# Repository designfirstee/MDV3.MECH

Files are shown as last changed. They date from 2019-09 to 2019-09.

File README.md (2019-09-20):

# MDV3.MECH

----
## What is MDv3?

Тhe First Open Design Metal Detector for the Industry. This is not a metal detector for treasure hunting or airport security. This is a metal detector for manufacturers, the recycling and processing industry.

- MDv3 can protect the output production from metal particles

- MDv3 can protect machines from broken off parts from the other machines on the production line

- MDv3 can protect the input of processing manufacturing

- MDv3 can be used as an Education and Research platform

----
## What files are in this repository?

1. Technical drawings - Mechanical drawings, describing the complete mechanical design of MDv3's reference design. MDv3 drawings follow worldwide accepted ISO standards for formatting.
  * MDv3 main technical drawing with BOM
  * Enclosure
  * Cover
  * Frame
  * Reel
2. 3D Models - STL files for 3D printing, ready for use with your favorite 3D slicer.

----
## Why?
# Innovation

*Industry 4.0 requires higher level of optimization and control by the user, therefore an open design industrial metal detector is the natural step in industrial engineering, for higher output manufacturing*

**Open design breaks the vendor dependencies** and enables the system integrators to create the optimum solutions for their end users

----
## Changelog
* 20-Sep-2019 Initial reference design of MDv3

----
## Thanks to
* Manoel Yanev - For being able to turn DesignFirst's concept of MDv3 into mechanical design after studying the previous MDv2 design
* Ivan Petrov - For testing together one of the first MDv3 prototypes (internal codenames - MDv3 Red and MDv3 White)
* Mitko Vasilev, Georgi Tonchev - For the feedback during publication of the design files and DesignFirst's website

----
# Learn more at [https://designfirst.eu](https://designfirst.eu).

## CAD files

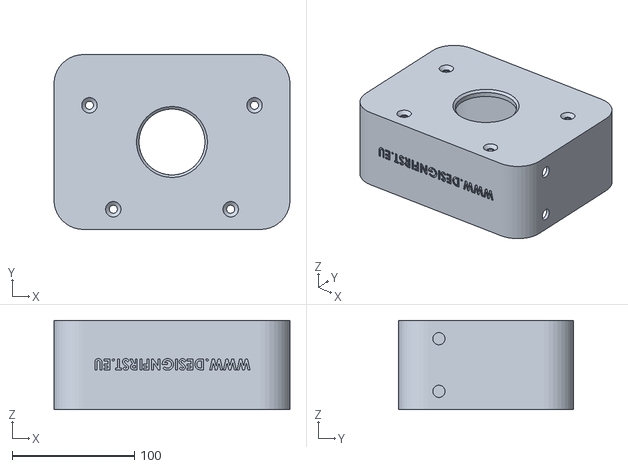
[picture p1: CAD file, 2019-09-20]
3D-models/MD-3-00.00.00.01.STL
193.0 x 143.0 x 73.0

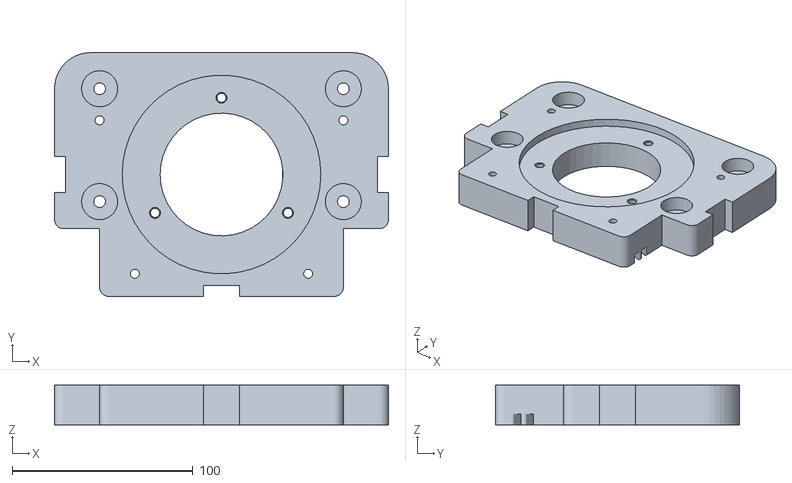
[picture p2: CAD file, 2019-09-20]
3D-models/MD-3-01.00.00.01.STL
185.0 x 135.0 x 22.0

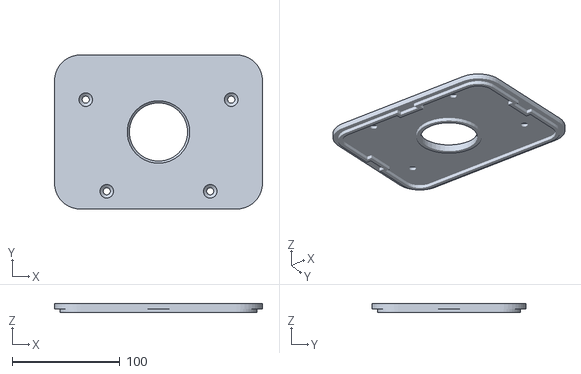
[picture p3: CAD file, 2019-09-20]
3D-models/MD-3-00.00.00.02.STL
193.0 x 143.0 x 8.00

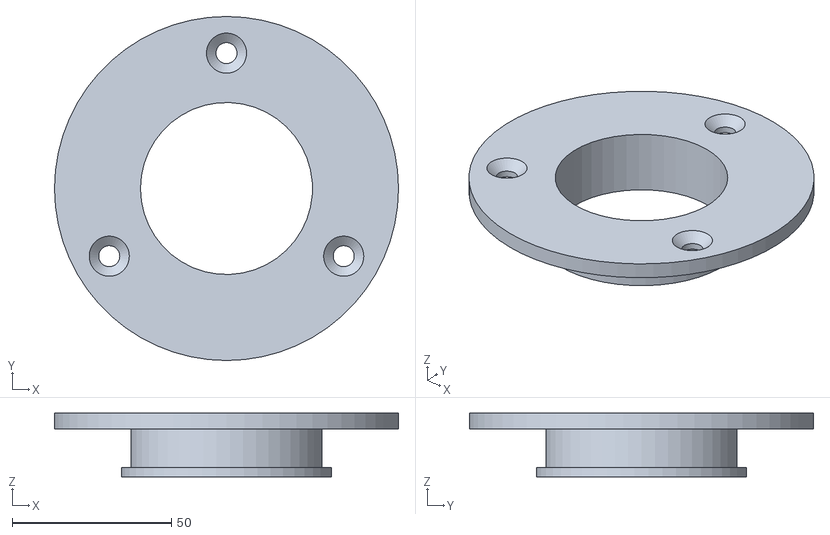
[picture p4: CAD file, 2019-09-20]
3D-models/MD-3-01.00.00.02.STL
108.0 x 108.0 x 20.0

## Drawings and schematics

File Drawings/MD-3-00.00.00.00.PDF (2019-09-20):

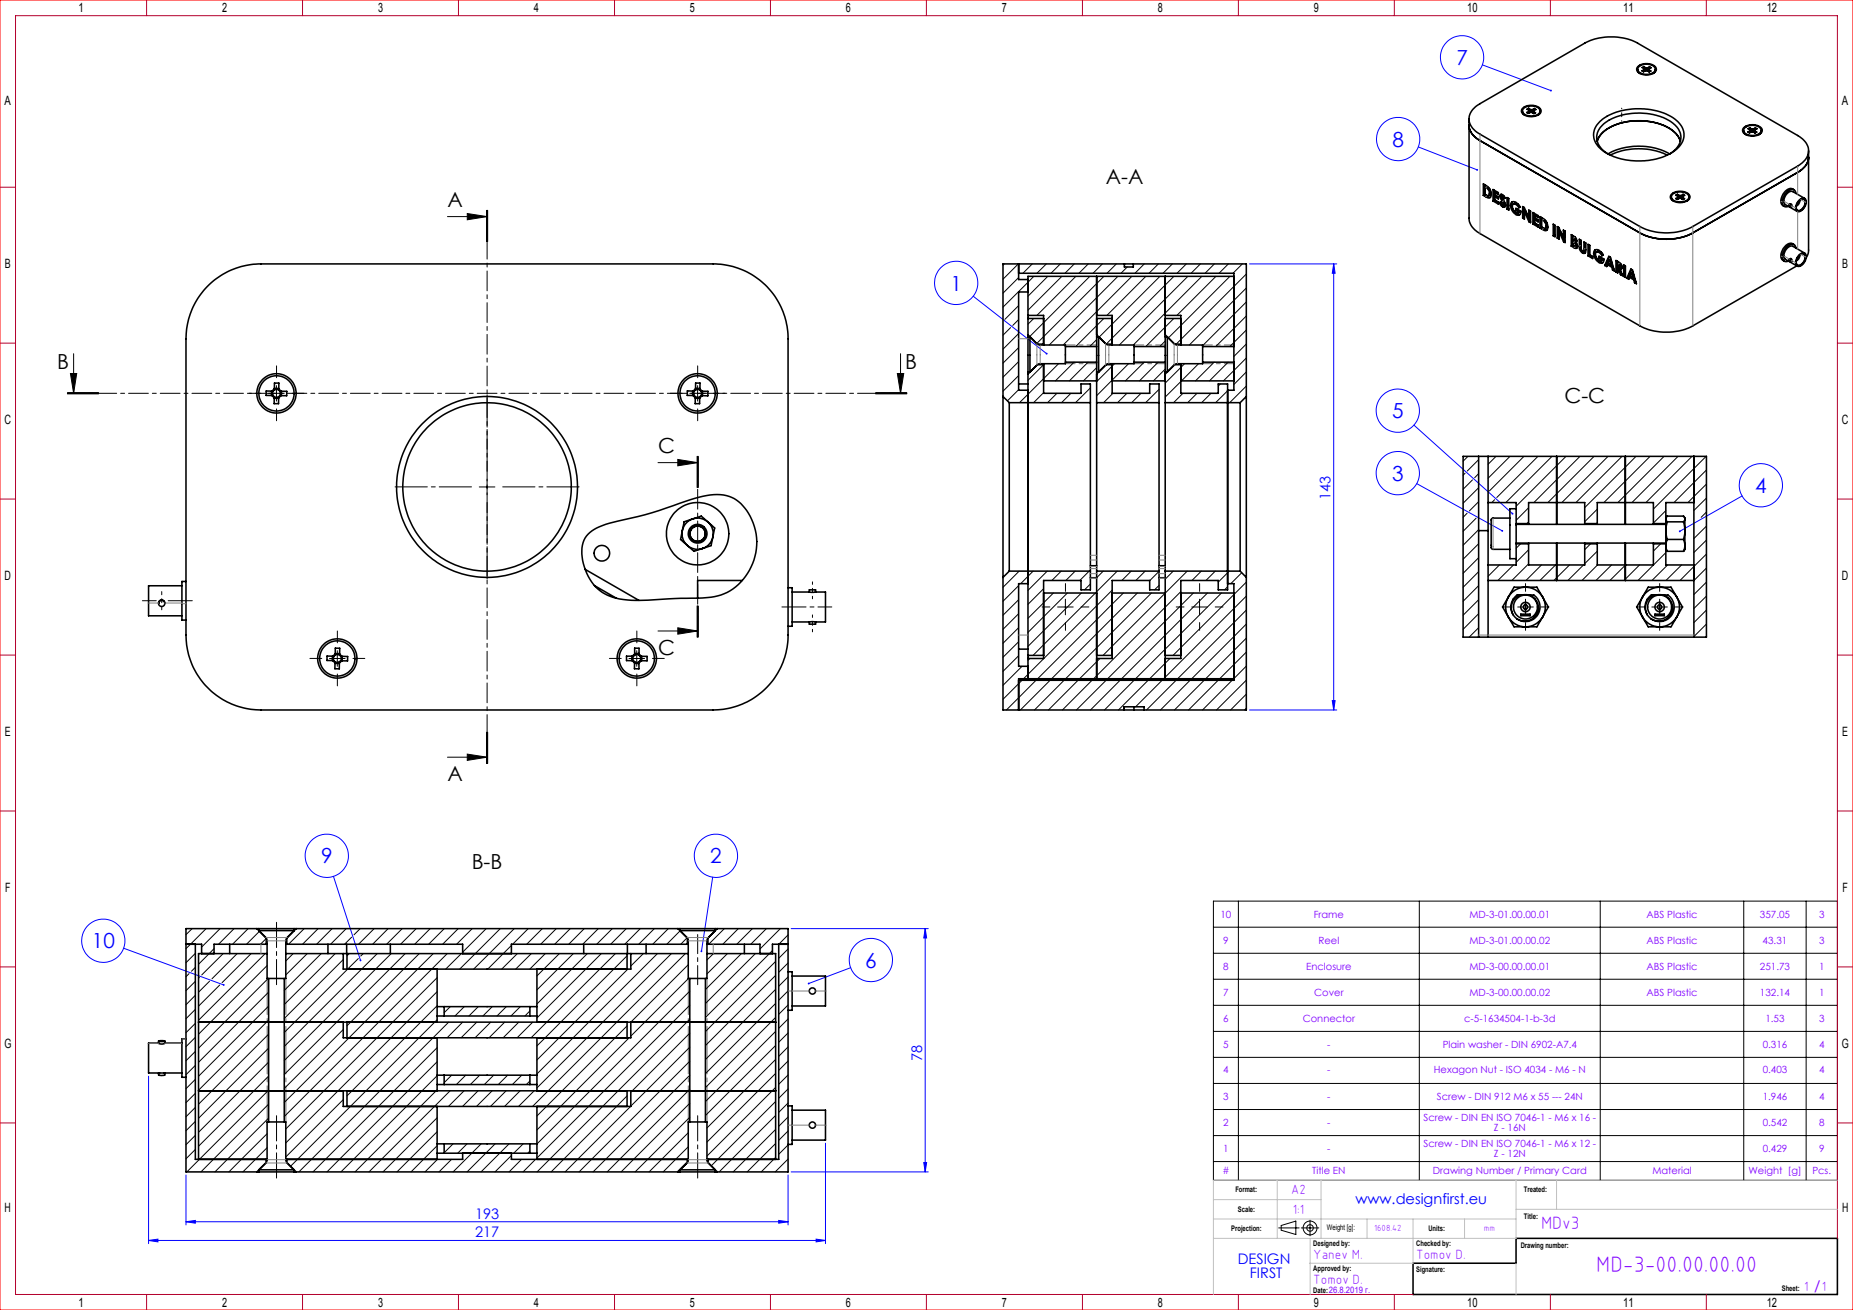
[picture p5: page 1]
Weight [g]:

10 | Frame | MD-3-01.00.00.01 | ABS Plastic | 357.05 | 3
9 | Reel | MD-3-01.00.00.02 | ABS Plastic | 43.31 | 3
8 | Enclosure | MD-3-00.00.00.01 | ABS Plastic | 251.73 | 1
7 | Cover | MD-3-00.00.00.02 | ABS Plastic | 132.14 | 1
6 | Connector | c-5-1634504-1-b-3d | | 1.53 | 3
5 | - | Plain washer - DIN 6902-A7.4 | | 0.316 | 4
4 | - | Hexagon Nut - ISO 4034 - M6 - N | | 0.403 | 4

3 | - | Screw - DIN 912 M6 x 55 --- 24N | | 1.946 | 4
2 | - | Screw - DIN EN ISO 7046-1 - M6 x 16 -Z - 16N | | 0.542 | 8
1 | - | Screw - DIN EN ISO 7046-1 - M6 x 12 -Z - 12N | | 0.429 | 9

# | Title EN | Drawing Number / Primary Card | Material | Weight [g] | Pcs.
Format: | A2 | www.designfirst.eu | Treated:
Scale: | 1:1
DESIGN FIRST | Designed by: Yanev M. | Checked by: Tomov D. | Drawing number: MD-3-00.00.00.00 Sheet: 1 /1

Approved by: Tomov D. Date: 26.8.2019 г. | Signature:

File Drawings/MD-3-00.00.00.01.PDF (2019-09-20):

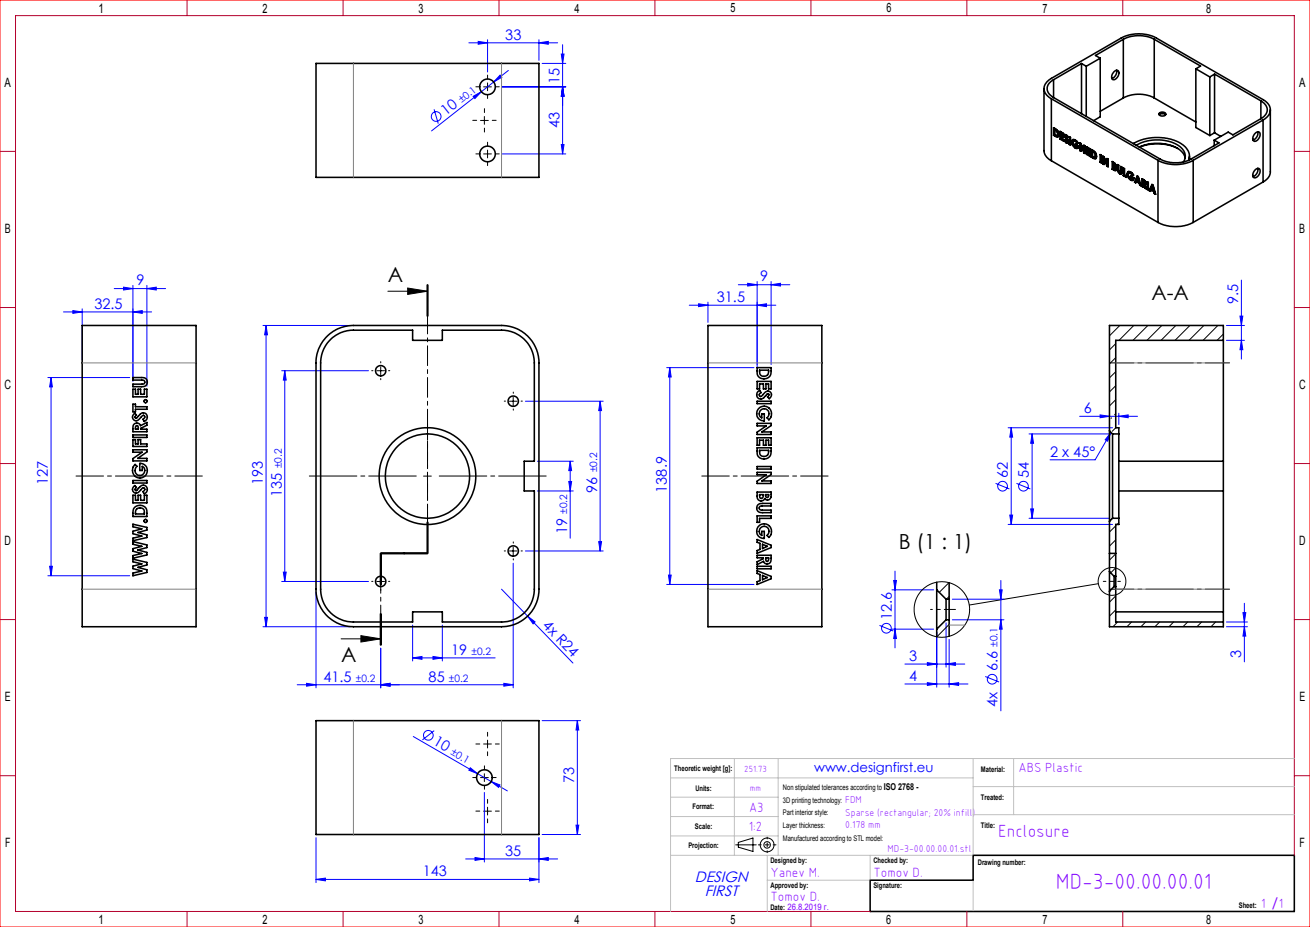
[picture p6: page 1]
Part interior style:; Sparse (rectangular; 20% infill)

Theoretic weight [g]: | 251.73 | www.designfirst.eu | Material: | ABS Plastic

Units: | mm | Non stipulated tolerances according to ISO 2768 -3D printing technology: FDM Layer thickness: 0.178 mm Manufactured according to STL model: MD-3-00.00.00.01.stl
Format: | A3
Scale: | 1:2 | | Title: Enclosure

Treated:

DESIGN FIRST | Designed by: Yanev M. | Checked by: Tomov D. | Drawing number: MD-3-00.00.00.01 Sheet: 1 / 1

Approved by: Tomov D. Date: 26.8.2019 г. | Signature:

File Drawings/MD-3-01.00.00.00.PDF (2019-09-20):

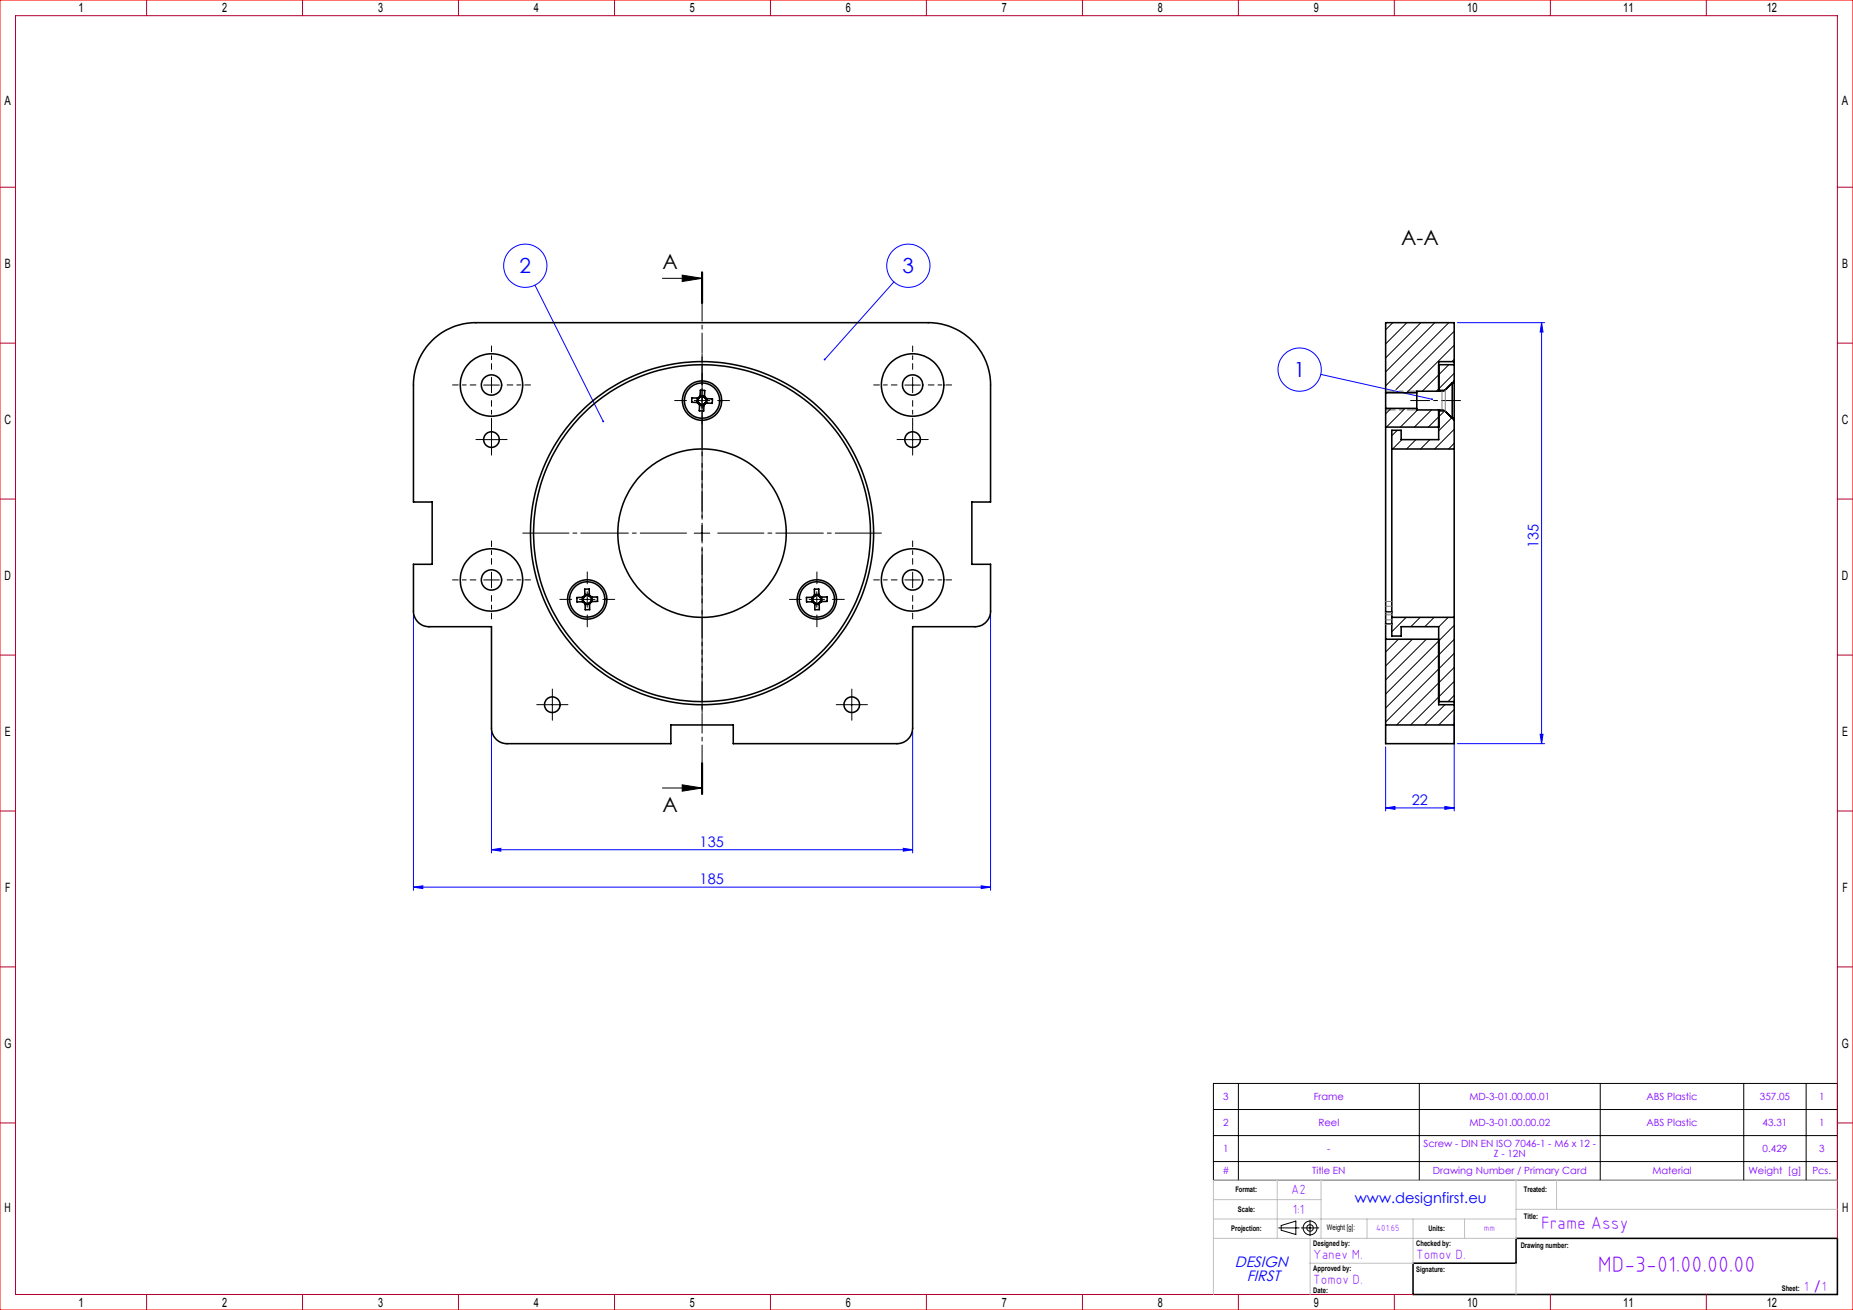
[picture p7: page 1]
Units:; Frame Assy

3 | Frame | MD-3-01.00.00.01 | ABS Plastic | 357.05 | 1
2 | Reel | MD-3-01.00.00.02 | ABS Plastic | 43.31 | 1
1 | - | Screw - DIN EN ISO 7046-1 - M6 x 12 -Z - 12N | | 0.429 | 3

# | Title EN | Drawing Number / Primary Card | Material | Weight [g] | Pcs.
Format: | A2 | www.designfirst.eu | Treated:
Scale: | 1:1
Projection: | | Weight [g]: | 401.65
DESIGN FIRST | Designed by: Yanev M. | Checked by: Tomov D. | Drawing number: MD-3-01.00.00.00 Sheet: 1 /1

Approved by: Tomov D. Date: | Signature:

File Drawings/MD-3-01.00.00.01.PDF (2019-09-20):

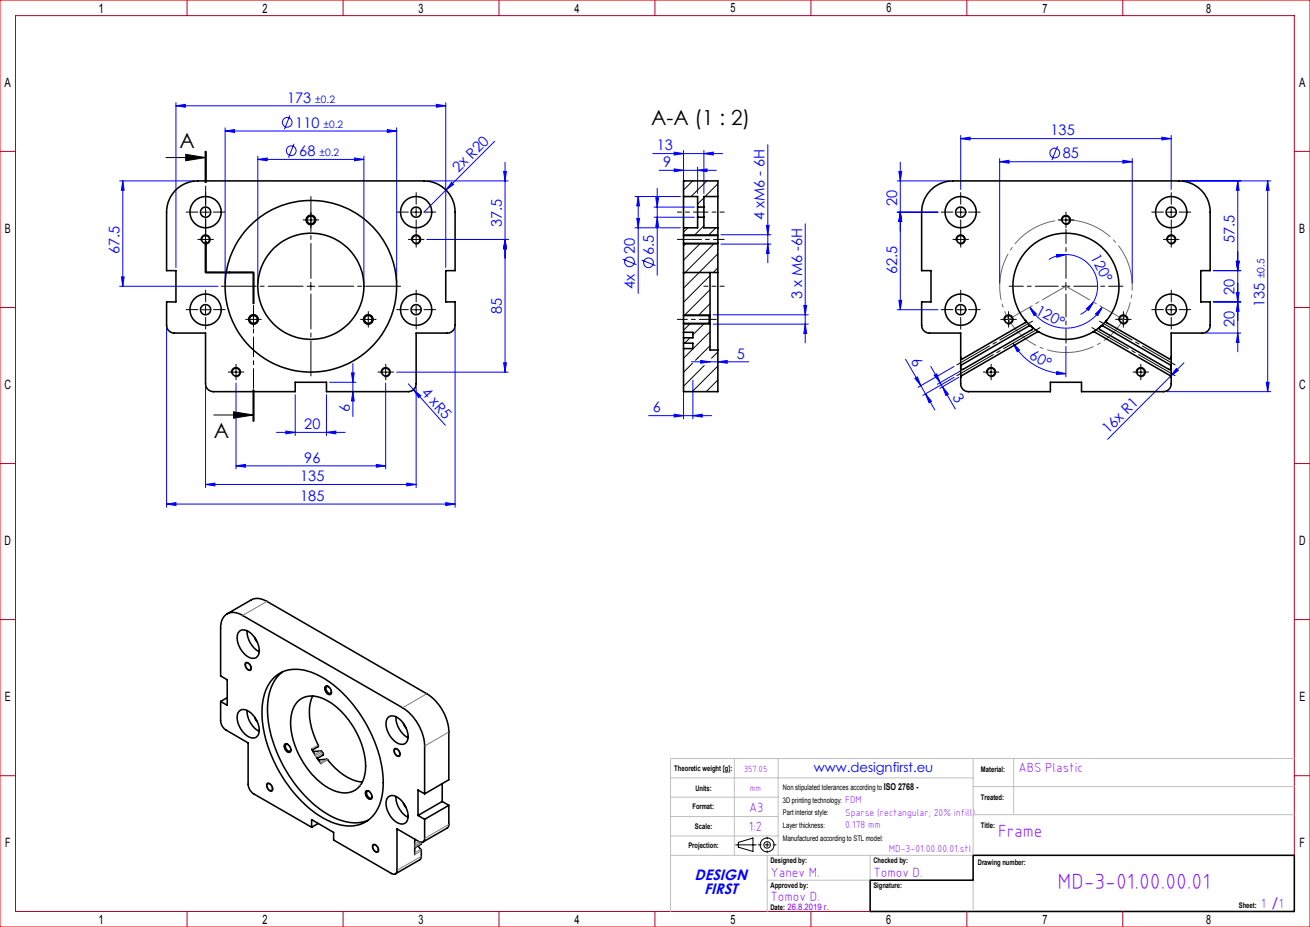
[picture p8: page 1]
Part interior style:; Sparse (rectangular; 20% infill)

Theoretic weight [g]: | 357.05 | www.designfirst.eu | Material: | ABS Plastic

Units: | mm | Non stipulated tolerances according to ISO 2768 -3D printing technology: FDM Layer thickness: 0.178 mm Manufactured according to STL model: MD-3-01.00.00.01.stl
Format: | A3
Scale: | 1:2 | | Title: Frame

Treated:

Projection:
DESIGN FIRST | Designed by: Yanev M. | Checked by: Tomov D. | Drawing number: MD-3-01.00.00.01 Sheet: 1 / 1

Approved by: Tomov D. Date: 26.8.2019 г. | Signature:

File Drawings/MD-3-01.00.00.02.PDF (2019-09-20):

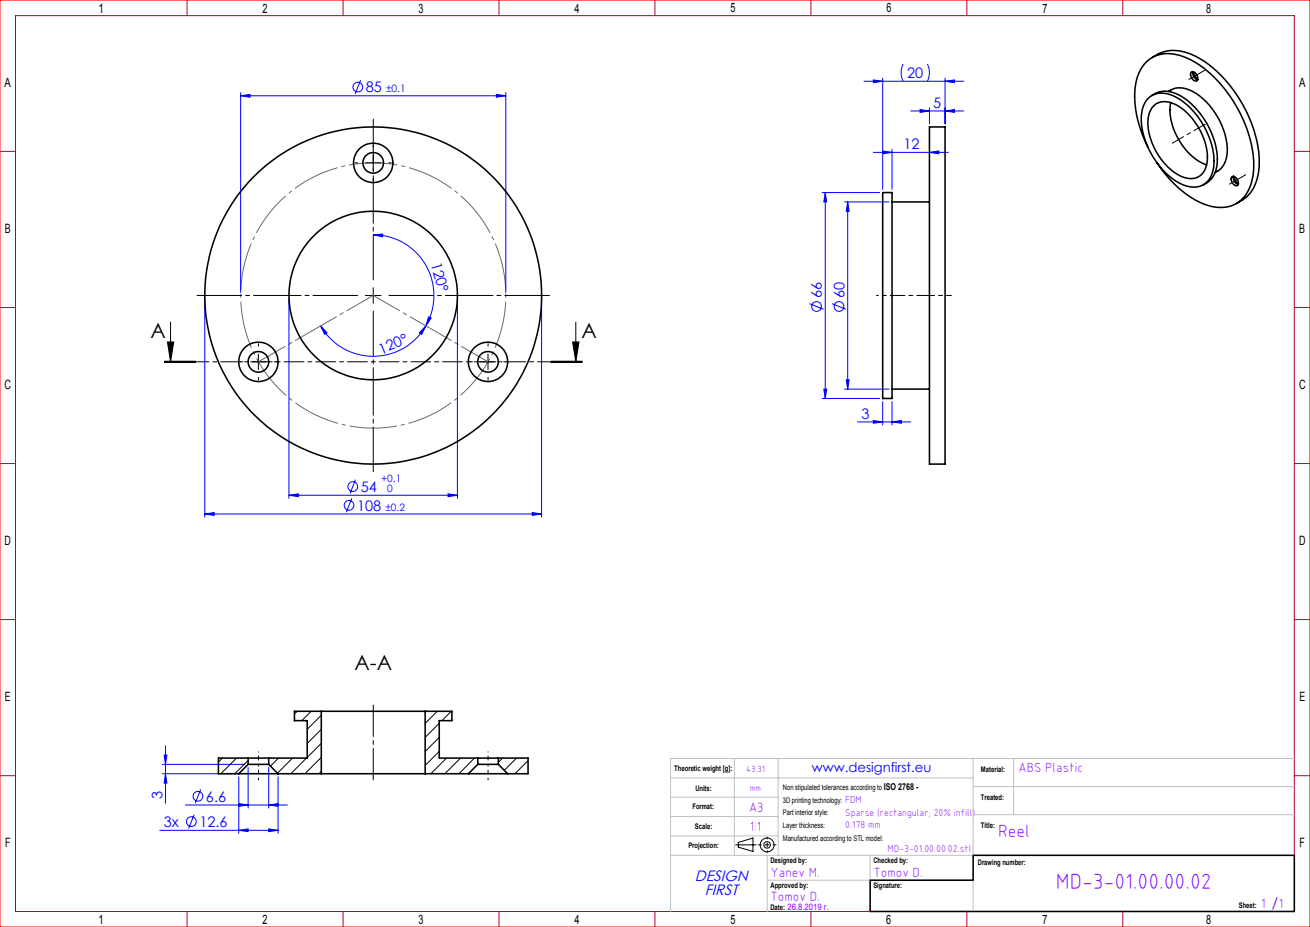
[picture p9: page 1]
Part interior style:; Sparse (rectangular; 20% infill)

Theoretic weight [g]: | 43.31 | www.designfirst.eu | Material: | ABS Plastic

Units: | mm | Non stipulated tolerances according to ISO 2768 -3D printing technology: FDM Layer thickness: 0.178 mm Manufactured according to STL model: MD-3-01.00.00.02.stl
Format: | A3
Scale: | 1:1 | | Title: Reel

Treated:

Projection:
DESIGN FIRST | Designed by: Yanev M. | Checked by: Tomov D. | Drawing number: MD-3-01.00.00.02 Sheet: 1 / 1

Approved by: Tomov D. Date: 26.8.2019 г. | Signature:

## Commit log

2019-09-20 Add technical drawings of the initial MDv3 reference design
    * Bill of materials is included in the main technical drawing
    * There are four mechanical parts in total
    - Enclosure
    - Cover
    - Frame
    - Reel
2019-09-20 Add 3D models of the initial MDv3 reference design, ready for 3D printing
    [MD-3-00.00.00.01.STL, MD-3-00.00.00.02.STL, MD-3-01.00.00.01.STL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]
